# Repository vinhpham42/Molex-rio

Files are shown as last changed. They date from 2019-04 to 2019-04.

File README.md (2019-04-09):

# Molex-rio
Pass through board that converts Roborio DIO, RSL, Relay, Analog In, and PWM to Molex latching connectors. On the underside, the board uses female header connectors that nest to the Roborio. 

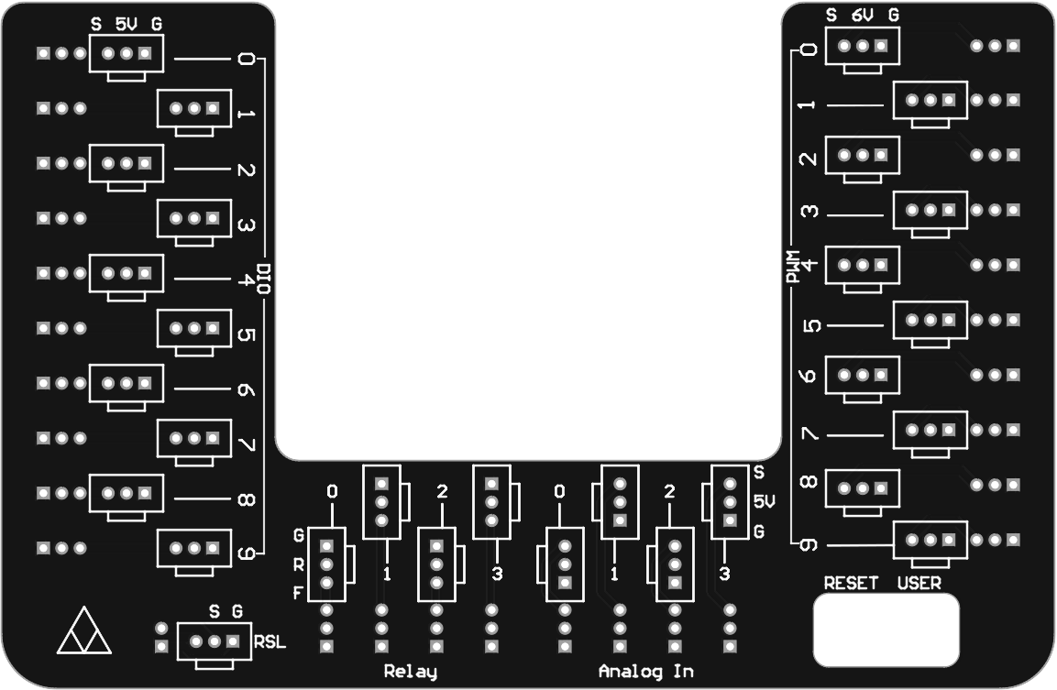
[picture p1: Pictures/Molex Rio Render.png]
Molex-rio


# BOM:
```
Molex Rio Digikey BOM
  Molex male pin header      QTY 29     	WM4825-ND
  Female header              QTY 29             S7001-ND
  Molex male housing         QTY 29             WM2901-ND
  Molex female crimp         QTY 87             WM2510-ND
  Crimper                    QTY 1              WM9999-ND	
```
This lists everything to get started, be sure to adjust accordingly.

# Installation:
1. Insert female headers into roborio.
2. For RSL, use flush cutters to cut off the third unused pin.
3. Place PCB on top of headers, making sure all pins aline with their repective holes. 
4. Once PCB is sitting flat, solder all headers to the PCB.(Using solder with higher amounts of flux will help)
5. Next, flip over the PCB and insert Molex Male Pin Header according to white print on PCB. 
6. Solder one leg of header, then check for straightness. 
7. Correct if needed, then repeat step 6, with each header. 
8. Use rubbing alcohol and a light brush to clean board if needed.

# Ordering:
1. Go to www.Digikey.com
2. Click on "Cart", then "View Cart"
3. Upload file named "Digikey Molex Rio Order" to the cart
4. When Propted for file Mapping, select "Quantity" then "Digi-Key Part Number" in the drop down box.
5. Lastly click on "Add to cart" to finish

# Molex Crimping:
Insturctions on how to crimp Molex connectors can be found in [Spectrum's recommended reading](http://spectrum3847.org/recommendedreading/) under Spectrium FRC Electrical Guide

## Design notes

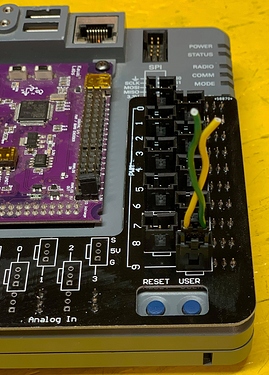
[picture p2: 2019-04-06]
Pictures/5f3a71b2f435d9684a8ece8d33353d8fce815d69_2_269x375.jpeg

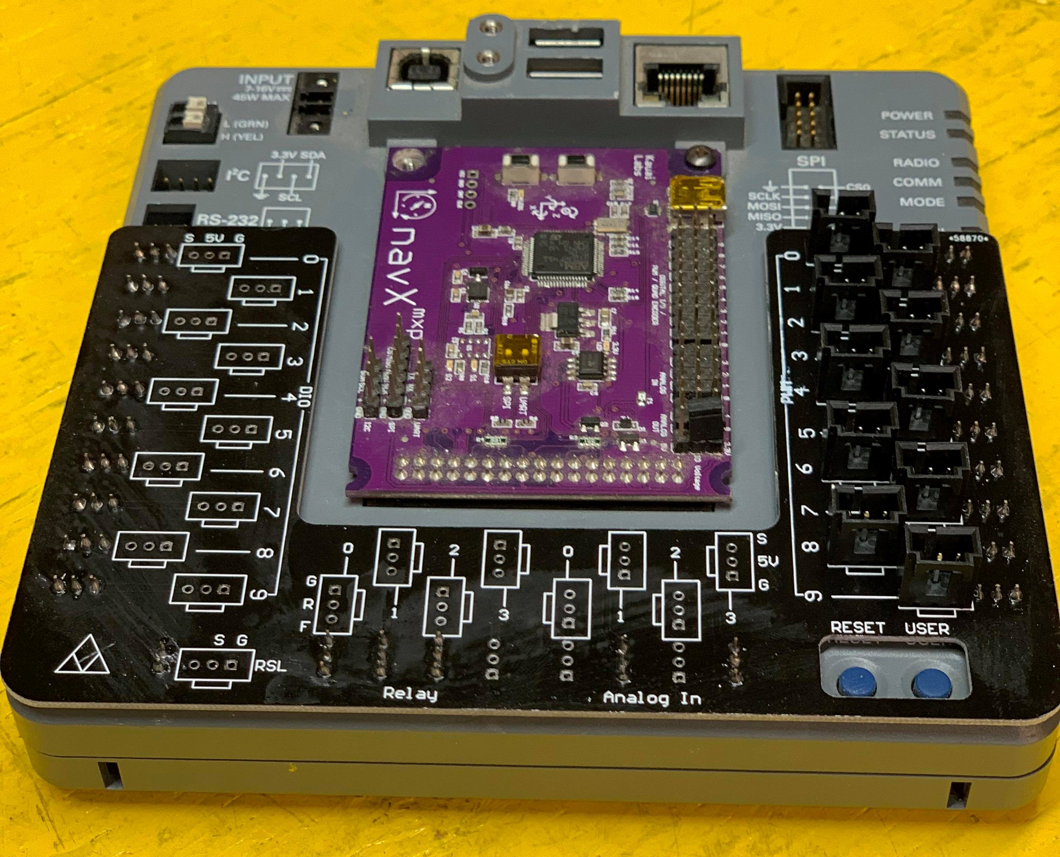
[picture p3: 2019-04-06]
Pictures/cc18de718c892b32b2d181744888e13cc649fdeb.jpeg

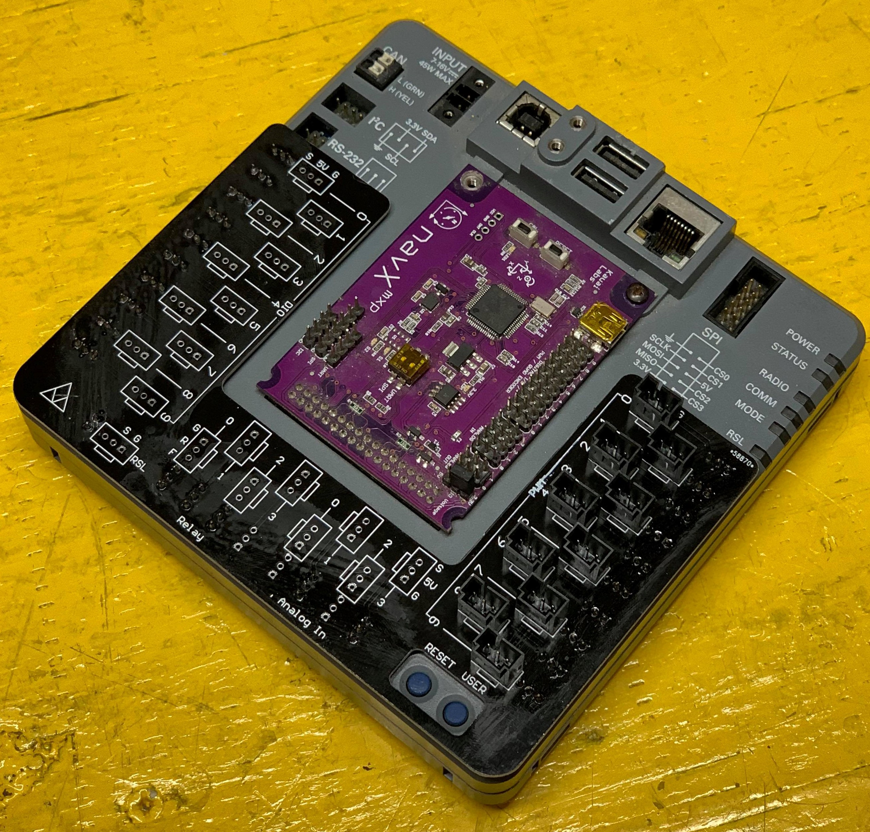
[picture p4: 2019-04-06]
Pictures/53208732_247022369583234_340738966980395008_n.jpg

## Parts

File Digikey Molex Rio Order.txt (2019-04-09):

29, WM4825-ND
29, S7001-ND	
29, WM2901-ND
87, WM2510-ND
1, WM9999-ND

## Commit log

2019-04-06 First upload
    Upload V1.0 Gerber files for MolexRio
    [Molex Rio Pro.GBL, Molex Rio Pro.GBO, Molex Rio Pro.GBP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]
2019-04-06 First Update
    Added BOM and first user directions
2019-04-06 Added Photos of the board
2019-04-09 Added and fixed README
    1. Added Extra part numbers for connector, crimp, and tooling
    2. Added Headers to each section
    3. Adding instructions for crimping from spectrum
2019-04-09 Added extra parts
    Added quantity and part numbers for housing, crimps, and tooling
2019-04-09 added extra note
    added "This lists everything to get started, be sure to adjust accordingly." under BOM
